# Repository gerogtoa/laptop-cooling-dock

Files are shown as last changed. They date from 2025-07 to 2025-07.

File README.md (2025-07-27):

# laptop-cooling-dock
My laptop tends to get very hot sometimes, so I decided to design a cooling dock that will hopefully help performance under sustained loads and save the battery from further damage.

Whenever I have multiple applications/tasks running, am playing games, or just have been using my laptop for a while, the heat buildup can eventually cause immense throttling of the CPU, and eventually even make the metal shell of the computer too hot to touch. For example, most of the time gaming I can reach 100 FPS; This will plummet to a mere 15 FPS after 20 minutes or so as the heat forces the computer to throttle, loosing up to half its performance. This is a known issue with Macbook Airs(especially since they lack any active or passive cooling systems). 

So here is my solution:



It addresses a few issues:

###  Heat Transfer 
- Macbook Airs have no cooling system, and even are designed to keep heat confined to the motherboard. While it helps with not burning your hands, it does cause throttling and immense heat buildup over time, which can still leak to the shell of the computer anyway.
- I plan to add thermal pads inside to help transfer heat from the motherboard to the bottom shell of the laptop. It might seem counterintuitive, however with a cooling system, heatsinking to the shell will allow heat to be taken out of the laptop.

###  Cooling
- My dock uses two Noctua NF-A6x15 5V fans to intake air and blast it against the bottom shell of the laptop, right where the motherboard is the hottest and heat will be localized. It is admittedly a little overkill, but something something the more CFM the merrier or something and two 60mm fans look cool and proportional.
- The fans intake from a large vent at the lower rear of the dock, which ensures most of the air is cold. The outtake vents are small in order to maintain high positive pressure. 

###  Ports
- The newer Macbook Airs notoriously have two USB-C ports and, more recently, a magsafe charging port. While it's not always a huge deal, adapters and dongles aways suck to use when they do become nessecary. I've included a Sabrent USB hub inside the dock that plugs into a USB-C port on the Macbook.
- The hub powers the two fans via two inwards-facing USB-A ports, with a further two facing outwards alongside an HDMI and USB-C port. An ethernet port is also accessible, and a Micro SD card slot as well.

###  User Experience
- Most consumer laptop stands are tall, ugly, and/or expensive. Also, what's with every laptop stand being so tall and/or angled? I don't understand the appeal and find it uncomfortable(when I tested it with placeholder wedges on my laptop).
- The goal of this dock was to be a thin and portable dock, and I'd say I've done a decent job with it. 

## Bill of Materials
|Item |Description |Vendor |Cost  |Quantity|Total |Link |
|---|---|---|---|---|---|---|
|Adhesive Cork Sheet 2500x200x1mm |To cover the bottom and top to prevent sliding |Amazon |$0.99 |1 |$0.99 |https://www.aliexpress.us/item/3256806952165170.html|
|Dust Filter 300x1000mm |To filter intake air of dust |Aliexpress |$0.99 |1 |$0.99 |https://www.aliexpress.us/item/3256809080527961.html|
|M4x12mm Ultra-Low Profile SHCS 20pc|To fasten the polycarb cover and USB hub cover to the body |Aliexpress |$0.99 |1 |$0.99 |https://www.aliexpress.us/item/3256806833766304.html|
|M4x25mm Ultra-Low Profile SHCS 20pc|To secure the fans to the body |Aliexpress |$0.99 |1 |$0.99 |https://www.aliexpress.us/item/3256806833766304.html|
|100x100x1.5mm thermal pad |To heatsink the CPU to the shell of the computer |Aliexpress |$0.99 |2 |$1.98 |https://www.aliexpress.us/item/3256808001308645.html|
|Noctua NF-A6x15 5V |To intake air to cool the bottom shell of the laptop |Amazon |$15.95|2 |$31.90|https://a.co/d/2aiRH9k |
|M4 Nylock Nuts 100pc |For general fastening |Aliexpress |$0.99 |1 |$0.99 |https://www.aliexpress.us/item/2251832612458814.html|
|Polycarb Cover |To interface the laptop shell with the body so it won't melt the 3D printed plastic|SendCutSend|$47.93|1 |$47.93|https://cart.sendcutsend.com/2ysmf3tukrza |
|USB fan splitter 2 - Dual Fan |To connect the two fans to one USB A port |Amazon |$8.95 |1 |$8.95 |https://a.co/d/iWLsJlx |
| | | | |Total:  |$95.71| |

BOM Last Updated: 7-27

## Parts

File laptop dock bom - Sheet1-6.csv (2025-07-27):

Item | Description | Vendor | Cost | Quantity | Total | Link
Adhesive Cork Sheet 15.7x31" | To cover the bottom and top to prevent sliding | Amazon | $12.99 | 1 | $12.99 | https://a.co/d/1KU3oZa
Dust Filter 400x300mm | To filter intake air of dust | Amazon | $8.99 | 1 | $8.99 | https://a.co/d/0loqiyE
M4x12mm BHCS 100pc | To fasten the polycarb cover and USB hub cover to the body | McMaster-Carr | $12.58 | 1 | $12.58 | https://www.mcmaster.com/91239a148/
M4x25mm Low Profile SHCS 25pc | To secure the fans to the body | McMaster-Carr | $9.37 | 1 | $9.37 | https://www.mcmaster.com/93070A109/
100x100x1.5mm thermal pad | To heatsink the CPU to the shell of the computer | Amazon | $9.99 | 1 | $9.99 | https://a.co/d/asofRSC
Noctua NF-A6x15 5V | To intake air to cool the bottom shell of the laptop | Amazon | $15.95 | 2 | $31.90 | https://a.co/d/2aiRH9k
Thunderbolt 4 USB C 1.6FT Cable | To get power from the laptop to distribute to the USB hub | Amazon | $14.90 | 1 | $14.90 | https://a.co/d/geJOPQc
M4x0.7mm 120 pack Nylock Nuts | For general fastening | Amazon | $6.99 | 1 | $6.99 | https://a.co/d/bJx2qE7
Polycarb Cover | To interface the laptop shell with the body so it won't melt the 3D printed plastic | SendCutSend | $47.93 | 1 | $47.93 | https://cart.sendcutsend.com/2ysmf3tukrza
USB fan splitter 2 - Dual Fan | To connect the two fans to one USB A port | Amazon | $8.95 | 1 | $8.95 | https://a.co/d/iWLsJlx
ABS Fillament 1KG White with Spool | For printing | BambuLabs | $22.99 | 1 | $22.99 | https://us.store.bambulab.com/products/abs-filament?id=41216786694280
 |  |  |  | Total: | $164.59

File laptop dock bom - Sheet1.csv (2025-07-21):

Item | Cost | Quantity | Total | Link
Adhesive Cork Sheet 15.7x19.7" | $9.99 | 1 | $9.99 | https://a.co/d/iCnySqv
Sabrent USB Hub 9 in 1 | $49.99 | 1 | $49.99 | https://a.co/d/fTbal9V
Dust Filter 400x300mm | $8.99 | 1 | $8.99 | https://a.co/d/0loqiyE
M4x12mm BHCS 100pc | $12.58 | 1 | $12.58 | https://www.mcmaster.com/91239a148/
M4x25mm Low Profile SHCS 25pc | $9.37 | 1 | $9.37 | https://www.mcmaster.com/93070A109/
100x100x1.5mm thermal pad | $9.99 | 1 | $9.99 | https://a.co/d/asofRSC
Noctua NF-A6x15 5V | $15.95 | 2 | $31.90 | https://a.co/d/2aiRH9k
1FT + 1FT usb c cable | $12.98 | 1 | $12.98 | https://a.co/d/fQpW5yh
 |  |  | $145.79

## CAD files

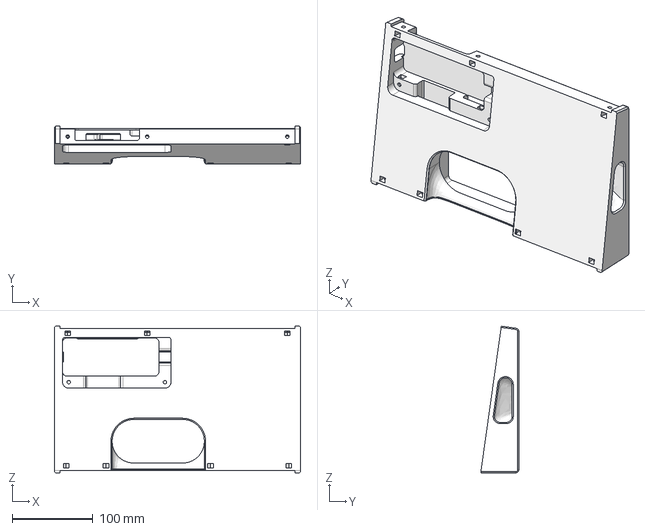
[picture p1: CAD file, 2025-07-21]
Onshape Link & .step Files/Body - Laptop Dock.step
304.1 x 46.8 x 181.2 mm

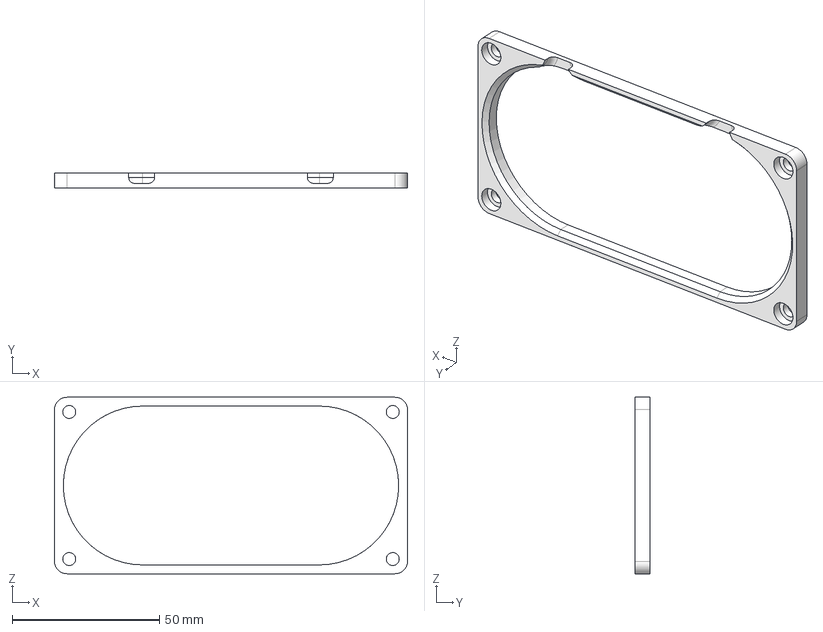
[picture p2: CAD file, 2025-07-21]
Onshape Link & .step Files/Fan Cover - Laptop Dock.step
120.0 x 5.00 x 60.0 mm

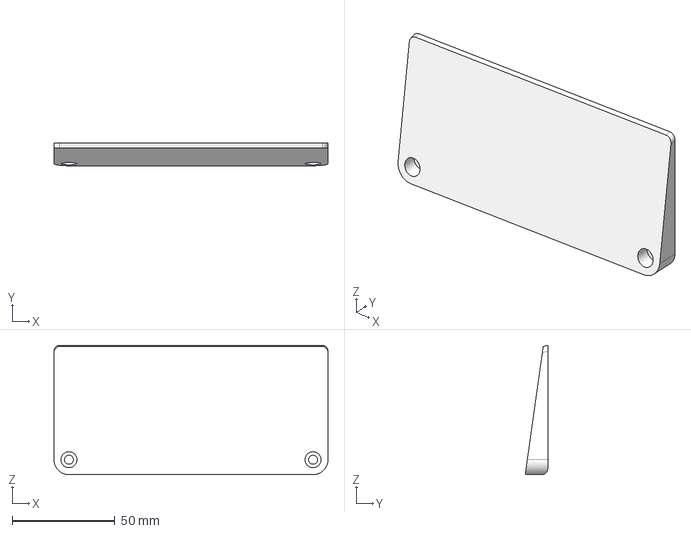
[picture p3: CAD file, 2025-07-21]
Onshape Link & .step Files/Hub Cover - Laptop Dock.step
133.6 x 11.0 x 63.1 mm

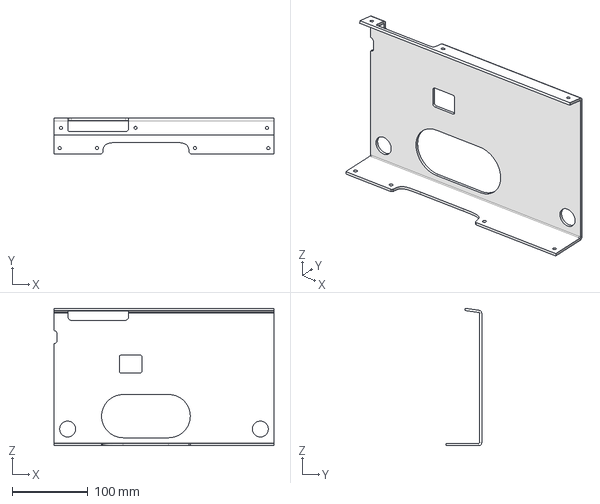
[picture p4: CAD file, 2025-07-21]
Onshape Link & .step Files/Polycarb Cover - Laptop Dock.step
290.1 x 46.8 x 181.2 mm

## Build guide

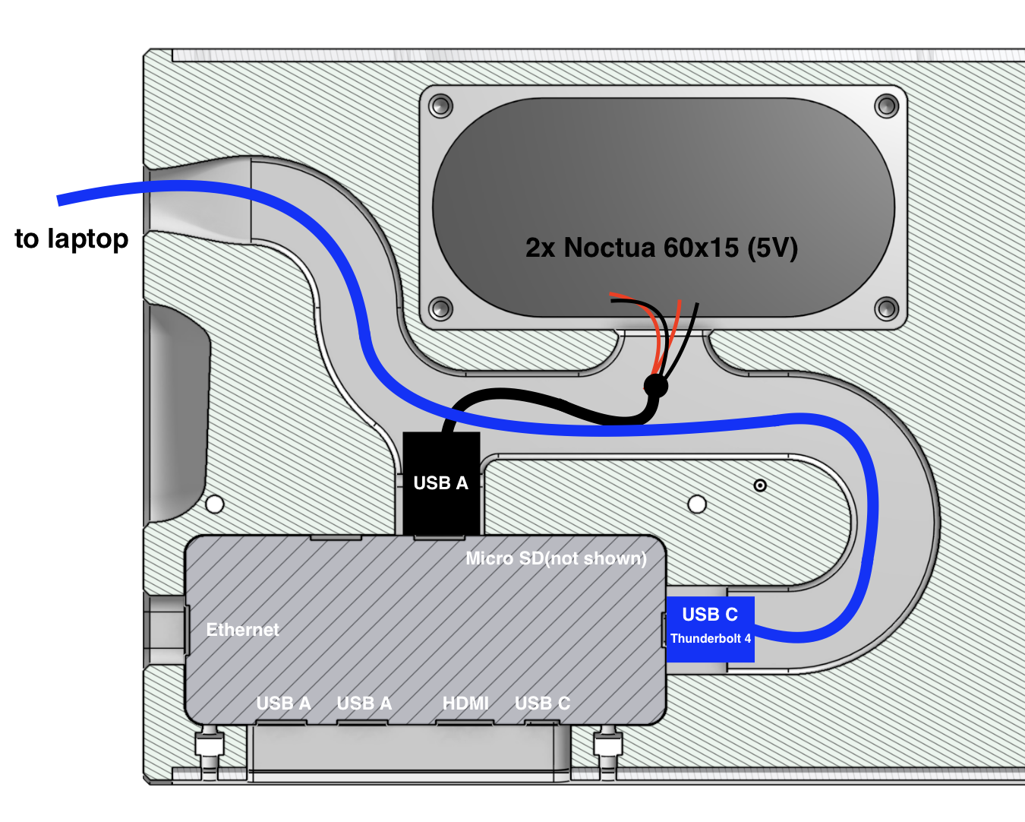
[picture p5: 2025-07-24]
Laptop Dock Wiring Diagram V1.png

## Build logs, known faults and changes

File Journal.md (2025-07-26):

## Hours
- Preliminary Design: 34 hours
- Build: 

---

So full disclosure I highkey didn't realize I needed to submit a journal until July 22nd so most of the stuff is being journalled on the 24th. My "entries" are based off my memory of my thoughts at the time and Onshape's incredibly accurate logging system(which logs EVERYTHING, even stuff as simple as showing/hiding parts down to minute which they happened).

# 7-14 | Determining Requirements | 1 Hour

I've finally decided to make a laptop stand after dropping to 10 FPS for the hundreth time or so. Did some research on previous solutions to Macbook Air overheating, and found LLT and Max Tech's videos particularly informative. They both used thermal pads to heatsink the CPU's heat to the metal shell of the laptop. Max went even further by adding a magsafe magnet inside and clipping on a third-party iPhone magsafe fan, which was kinda epic. I want to do something like that too with an active cooling system.

<br>

<h6 align="center"><i><small>Max Tech's Magsafe active cooling fan.</small></i></p></h6>
<br>
 
That method would definitely require a stand/housing for everything. I considered a proper heatsink and determined that it probably won't be nessecary given the already impressive performance increase and temperature decrease Max saw with just one baby fan and no proper heatsink as well. I think I will go ahead with two fans, probably from Noctua. A friend reccomended this brand to me and after some research it seems they have some of the best performing fans while also being very quiet, which is pretty cool. I also want to incorperate a USB hub of some kind since Macbook Airs notoriously have negative one ports. Will also need the hub to power the fans off the Macbook. 

So the current requirements are:
- Heatsink to the bottom shell of the laptop
- Use Noctua fans to actively cool the system
- Power the fans off the computer using a USB hub
- Have as many ports of the USB hub accessiable and usable

<br>As for the actual CAD, I made the document and that's about it.

<br>

<h6 align="center"><i><small>And it was all downhill from here.</small></i></p></h6>
<br>

# 7-15 | What the heck | 0.5 Hours

So uh, what the heck were we thinking...??


<h6 align="center"><i><small>What the helly??</small></i></p></h6>
<br>

# 7-16 | Locked In Behavior | 13.5 Hours

Today I decided to lock in and have finally made a kinda style I like. The original idea with the wood top was to match the color pallette of the Noctua fans and also provide a better contact surface for the hot underside of the laptop(since I think it would at the very least warp the 3D printed plastic), and has now been replaced with a bent polycarbonate sheet that I think is pretty cool. 



This currently only supports the back as the angle in theory lines up the front to contact the table as well, so it should be fully supported. However I realized that it would probably be wise to allow more room in the front, since I would actually rather have the USB hub ports near the front instead of all the way at the back. Also I don't think there is enough room for it anyway since I'm trying to keep the width the same as the Macbook itself.

<br>

<h6 align="center"><i><small>Some genuinely horrific never before seen "surfaces" were created as George attempted to surface model the intake vent for literally no reason at all</small></i></p></h6>
<br>

Eventually, I landed on a nice and simple intake duct, with an extra slot(-ish thing?) to accomodate a grille or dust filter.

<br>

<h6 align="center"><i><small>It also proved to be incredibly parametric!</small></i></p></h6>
<br>

I thus began on the outtake ducts. I initally was thinking of ways it could be functional yet asthetic at the same time, and decided that having channels exposed on the top of the 3D printed plastic but capped by the polycarb could look super cool. I placed an outtake vent at each side, which I plan on connecting to in some cool fashion.

<br>

<br>

# 7-17 | Locked Out Behavior | 3.5 Hours

This was truly a traumatic day. I started off by completely redoing the vents for no reason at all which ended up being a huge ugly mess/waste of time that I ended up rolling back anyway.

<br>

<h6 align="center"><i><small>Why would he do this?</small></i></p></h6>
<br>

Yeah those were pretty tragic. But what was by far worse than that was my first attempt at the outtake channels...

<br>

<h6 align="center"><i><small>Terrible.</small></i></p></h6>
<br>

I eventually moved on to a much more sensible vent/channel design...

<br>

<h6 align="center"><i><small>Simplicity is a very beautiful thing! Now with ∞% more fasteners.</small></i></p></h6>
<br>

Another somewhat good outcome was finally getting rid of that dividing line. Since I have an BambuLabs A1 Mini 3D printer, I originally split it to fit on the print bed. But then I realized, I currently have my robotics team's P1S at my house for the summer, so I could just use that. Confirming the viability of a single piece print also essentially locked in the width and height, as literally neither could increase without it going over the print volume constraints.

<br>

<h6 align="center"><i><small>Yikes...</small></i></p></h6>
<br>

# 7-20 | Adding the USB Hub | 3.5 Hours

With the intake and outtake vent debacles finally sorted out, I started integrating the USB hub. It was actually more challenging to find one than I thought it would be, since a lot of hubs were either too large with too many ports, too small with too little ports, or just right but only having ports on one side; I needed a "double sided" hub since the fans would plug into it as well internally. Eventually a friend reccommended the Sabrent 9 in 1 USB hub which he owned and found to be of high quality. A CAD model also existed in the Onshape public library! Super convenient. However, it did become a challenge to try and package, requiring me to eventually change the size, shape, and angle of the whole dock. Luckily things were pretty parametric and worked out nicely.

<br>

<br>

After some effort, I think I came up with a pretty elegant solution. By flipping the hub upside down, there can be two inwards facing USB A ports to power the fans. On the front, another two USB A ports are present alongside a USB C and HDMI port. Ethernet is accessible on the side.

<br>

<br>

# 7-21 | Internal Routing | 4 Hours

Some evil events transpired today. I realized I did not structure my design with internal routing in mind; I started with a billet and subtracted, rather than a hollow shell and added.

<br>

<h6 align="center"><i><small>The initial design for the USB A to fan channels.</small></i></p></h6>
<br>

Added the input for the hub from the laptop.

<br>

<br>

Ended in a nice spot for today. Also somehow managed to squeeze in a top access hole for the inwards facing Micro SD card slot! I think I'm pretty much done, and have started assembling a Bill of Materials! 

<br>

<h6 align="center"><i><small>Narrator: "He was in fact, nowhere near done..."</small></i></p></h6>
<br>

# 7-23 | Holy Scope Creep | 7.5 Hours

Some friends suggested I add a powerbank, which I think is a super cool and amazing idea. My laptop suffers from abysmal battery health(as a product of the overheating!), so either powering the fans off a powerbank or charging the laptop directly could be pretty awesome.

<br>

<h6 align="center"><i><small>Housing for the iNiu P55-E2 10,000mAh 45W powerbank.</small></i></p></h6>
<br>

I do have a lot of questions of how this whole system would work, though. How would the powerbank power things? I originally wanted it to be able to charge the computer and power the fans through the USB hub, but how would that work if the computer was also meant to power the fans through the hub? If I simply plugged/unplugged the powerbank/laptop depending on which input I desired, then when powered through the powerbank, I would not be able to use the the ports on the hub for data transfer with the computer, which was kind of nessecary if I wanted to have stuff plugged in like a USB A mouse and earbuds simultaneously. I went through dozens of different adapters trying to make this system work, but it was just a huge pain and pretty much impossible without some custom PCB that I am just not ready to design at this point. 

<br>

<h6 align="center"><i><small>Wiring diagram for the power flow of the system after realizing it was completely cooked.</small></i></p></h6>
<br>

Eventually after running in circles for literal hours and going nowhere, I finally decided to drop the powerbank idea. I'd imagine the dock will sit at my desk next to my laptop charger most of time anyway, so a portable powerbank would just not be nessecary. Adding a slot to hold one is still on the table for travel.

While talking with a friend on how to approach wiring, I was introduced to the difference between USB 2.0 and Thunderbolt 4, which is, to say the least, a huge difference. It became clear that in order to accommodate Thunderbolt 4 cables(with their thicker wires, beefier connectors, and larger bend radii, etc.), a major redesign of the internal routing would be needed. 

<br>

<h6 align="center"><i><small>Before(left) and after(right) of the internal routing redesign. Went through several variations and changes to the actual wires/connectors as well, but main improvements include larger channels, better wiring for the fans, larger bend radii.</small></i></p></h6>
<br>

I've also been absolutely tweaking out over finishing the BOM because of the bent polycarb sheet. When I designed it, I used Onshape's sheet metal model tools, but didn't form the bends properly, and thus the model/.dxf exports were invalid when I uploaded them to quote on SendCutSend. But even before I realized that, the .dxf files were already getting broken for no reason at all either when exported from Onshape or when converted from a .step on SendCutSend's instant quote software. I would have to re-import the .dxf files into Onshape and manually fix them, just for it to again not work because of "unenclosed spaces" when there were zero gaps. I eventually reached out to support and am awaiting a response. 

<br>

<h6 align="center"><i><small>Pain. Suffering.</small></i></p></h6>
<br>

# 7-24 | Done? | 0.5 Hours

I finally got my share link approved for the SendCutSend order, allowing me to finally finish the Bill of Materials.

That's all for now!



### Future plans:
- Add room for a powerbank that is not hooked up to the rest of the system
- Storage for a mousepad
- Finally realize that the above two bullet points are more scope creeps and will induitably lead to copious amounts of pain and suffering

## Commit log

2025-07-21 Rename Body - Laptop Dock.step to Onshape Link & .step Files/Body - Laptop Dock.step
    [Body - Laptop Dock.step]
2025-07-21 Rename Fan Cover - Laptop Dock.step to Onshape Link & .step Files/Fan Cover - Laptop Dock.step
    [Fan Cover - Laptop Dock.step]
2025-07-21 Rename Hub Cover - Laptop Dock.step to Onshape Link & .step Files/Hub Cover - Laptop Dock.step
    [Hub Cover - Laptop Dock.step]
2025-07-21 Rename Polycarb Cover - Laptop Dock.step to Onshape Link & .step Files/Polycarb Cover - Laptop Dock.step
    [Polycarb Cover - Laptop Dock.step]
2025-07-21 Update and rename laptop dock bom - Sheet1.csv to Laptop Dock BOM.csv
    [Laptop Dock BOM.csv]
2025-07-24 Update and rename laptop dock bom - Sheet1-3.csv to Laptop Dock BOM.csv
    [Laptop Dock BOM.csv]
2025-07-25 Update and rename laptop dock bom - Sheet1-4.csv to Laptop Dock BOM.csv
    [Laptop Dock BOM.csv]
2025-07-25 Update Laptop Dock BOM.csv
    [Laptop Dock BOM.csv]
2025-07-27 Update and rename laptop dock bom - Sheet1-5.csv to Laptop Dock BOM
2025-07-27 Update laptop dock bom - Sheet1-6.csv
    [laptop dock bom - Sheet1-6.csv]
2025-07-27 Update and rename laptop dock bom - Sheet1-6.csv to Laptop Dock BOM
2025-07-27 Update and rename laptop dock bom - Sheet1-7.csv to Laptop Dock BOM.csv
    [Laptop Dock BOM.csv]
2025-07-27 Update and rename Laptop Dock BOM - Sheet1-8.csv to Laptop Dock BOM.csv
    [Laptop Dock BOM.csv]
